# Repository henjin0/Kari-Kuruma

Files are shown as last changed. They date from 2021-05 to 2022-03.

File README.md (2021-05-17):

# Kari-Kuruma
Kari-Kuruma:Easy Constructing toy car for Prototyping.

簡単に組み立てられるプロトタイピング向けラジコンカー車体

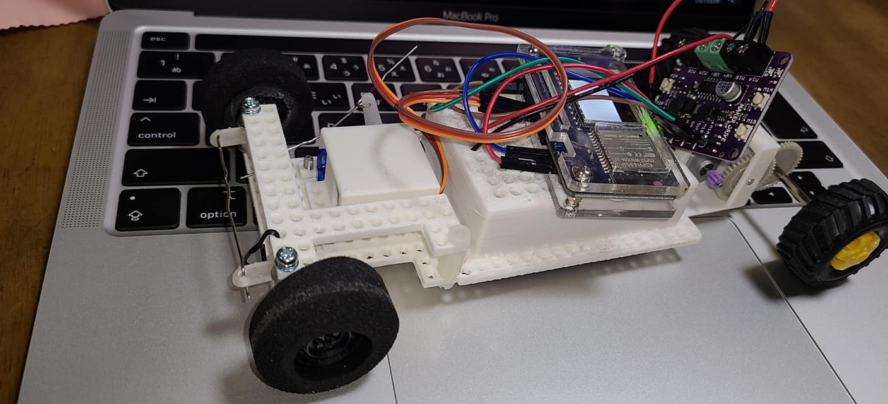
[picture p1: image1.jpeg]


# What is Kari-Kuruma?
Kari-Kuruma is an A5 size toy car body that can be created using 3D printing. The Kari-Kuruma can be easily assembled with Raspberry Pi or other circuit boards and various sensors such as cameras.
Also, parts that are not available through 3D printing can be easily obtained from sources such as TAMIYA.
This makes it possible to avoid as much as possible the risk of parts being out of supply.

Kari-Kurumaは3Dプリンティングで作成できるA5サイズのプロトタイピング向けラジコンカー車体で、Raspberry Piなどの基板やカメラなどの各種センサ類の組付けが容易にできます。
また、3Dプリンティングで手に入らない部品はTAMIYAなどから簡単に入手でき、部品のディスコンなどに振り回されないようにしました。

# Other assembly parts
The links are examples.

リンク先は一例です。

- [TAMIYA GEAR SET Item No:70239 (42T/12T)](https://www.tamiya.com/japan/products/70239/index.html)
- [TAMIYA AO-1001 FA-130 motor](https://www.tamiya.com/japan/products/94380/index.html)
or
- [MABUCHI FA-130RA motor](https://www.mabuchi-motor.co.jp/motorize/branch/motor/)
- [motor driver(何かしらのモータドライバ)](https://www.cytron.io/p-maker-drive-simplifying-h-bridge-motor-driver-for-beginner)

- [TowerPro SG-90 Servo motor](https://akizukidenshi.com/catalog/g/gM-08761/)
- [TAMIYA THREADED SHAFT SET (only using φ3(23mm))](https://www.tamiya.com/japan/products/70182/index.html):2 screws(ネジ2本)
- [M3x18 Machine Screw(M3x18 mmの機械ネジ)](https://www.amazon.com/dp/B07D5V279W/ref=cm_sw_em_r_mt_dp_WT2JPND0KJ9E13ZG9NET):2 screws(ネジ2本)
- [M3x10 Machine Screw(M3x10 mmの機械ネジ)](https://www.amazon.com/dp/B07MF3RN7M/ref=cm_sw_em_r_mt_dp_0NSJJ36C3078DVDZV988):6 screws(ネジ6本)
- [Wire link Arm A and B（Please see below.）](https://github.com/henjin0/Kari-Kuruma#how-to-build-wire-link-arm)

- [4 Slot AAA Battery Holder](https://akizukidenshi.com/catalog/g/gP-00735/)

# How to make Wire link arm.
Wire link arm are made two paper clips(ex:https://www.askul.co.jp/p/8188431/).

2つのペーパークリップ(針金クリップ)をつかってWire link armを作ります。

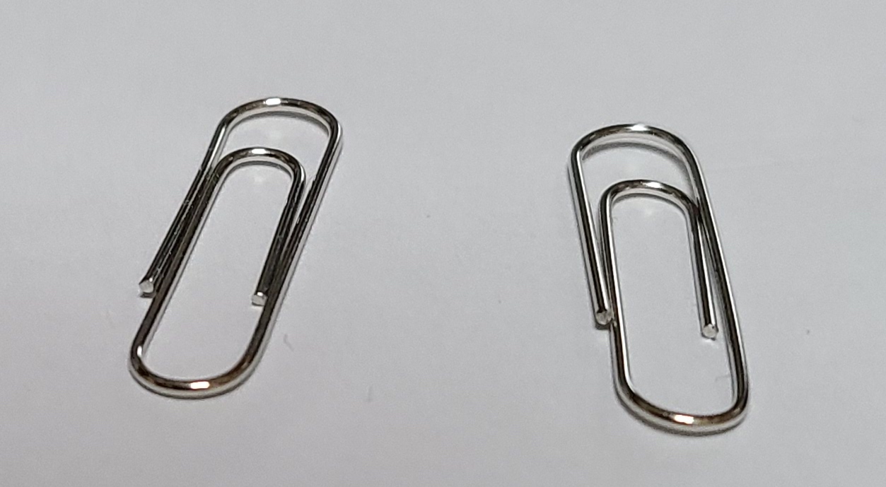
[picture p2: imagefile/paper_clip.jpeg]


1. Bend two paper clips into straight bar wires. 2つのクリップを折り曲げて直線状にします。

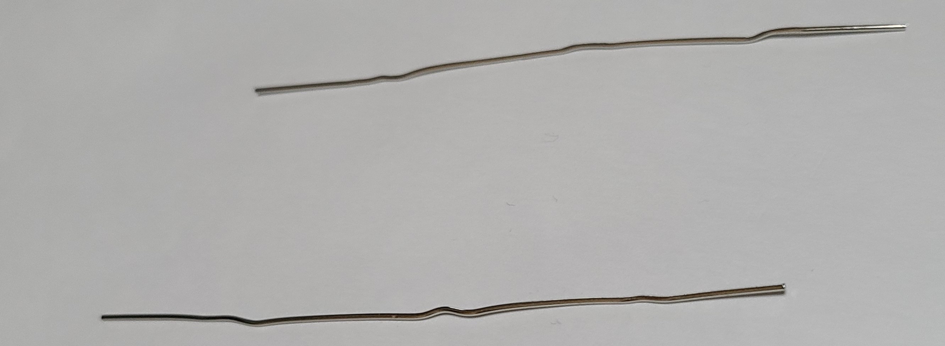
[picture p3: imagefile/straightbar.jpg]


## How to make Wire link arm A

2. Cut one wire to length of about 64 mm. 一つをおおよそ64 mmにカットします。

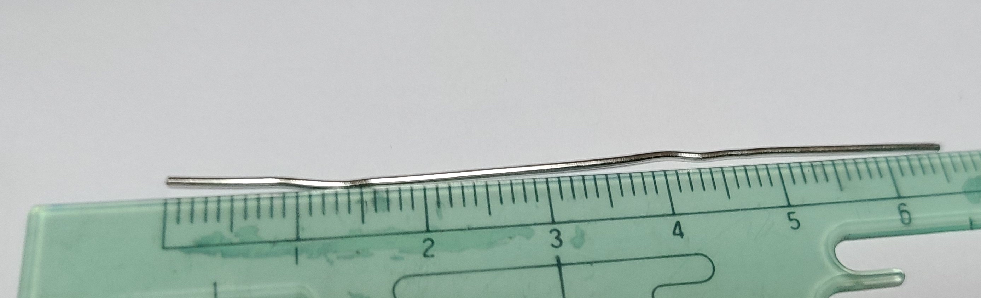
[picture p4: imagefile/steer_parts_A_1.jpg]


3. Bend 64 mm wire as shown in the figure below. 64 mmにカットしたものを下の写真のように折り曲げます。

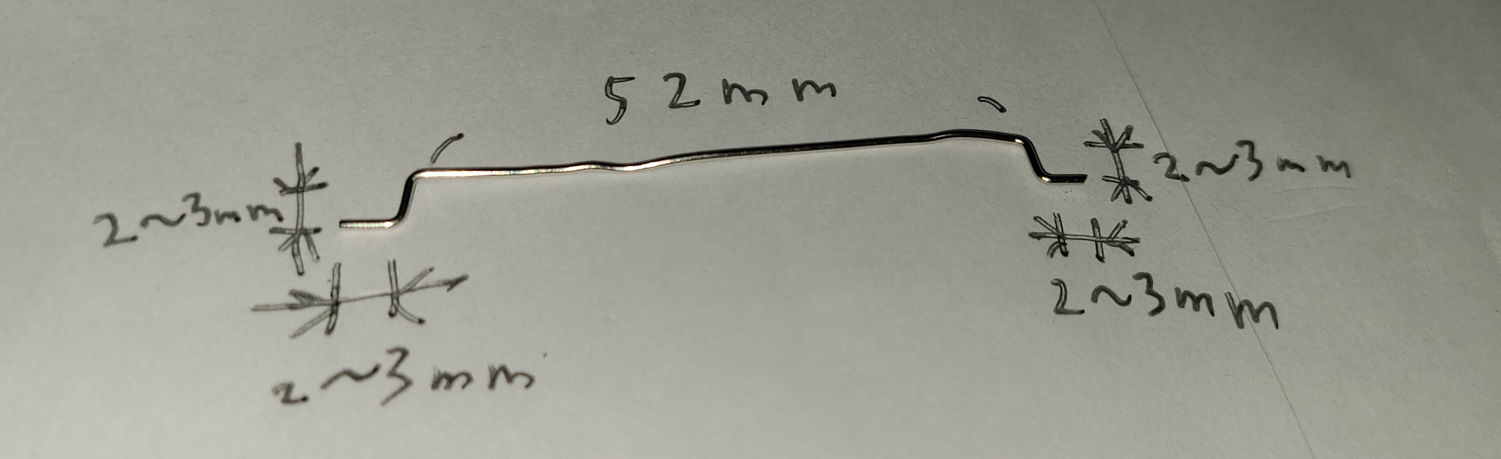
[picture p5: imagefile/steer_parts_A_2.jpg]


## How to make Wire link arm B

4. Cut another wire to length of about 52 mm. もう一つをおおよそ52 mmにカットします。

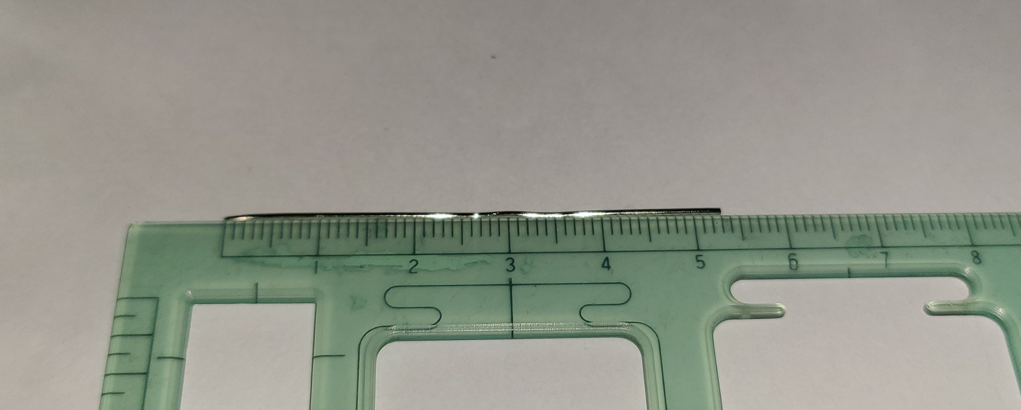
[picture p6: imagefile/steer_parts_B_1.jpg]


5. Bend another wire as shown in the figure below. 52 mmにカットしたものを下の写真のように折り曲げます。

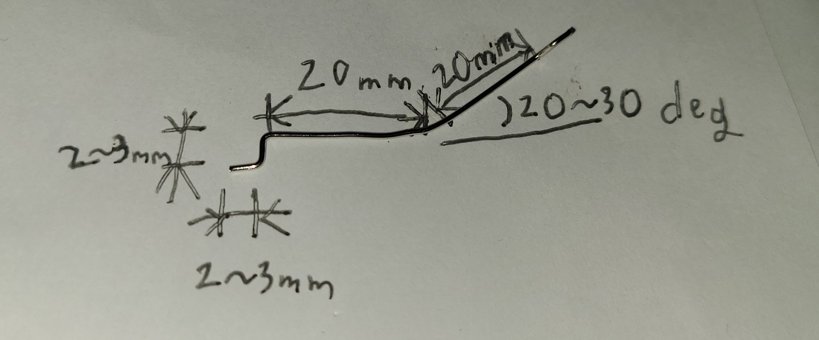
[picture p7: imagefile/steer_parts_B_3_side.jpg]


After bending to about 20 degrees parts, bend wire as shown in the figure below. 20度に折り曲げた先の部位は下の写真のように折り曲げます。

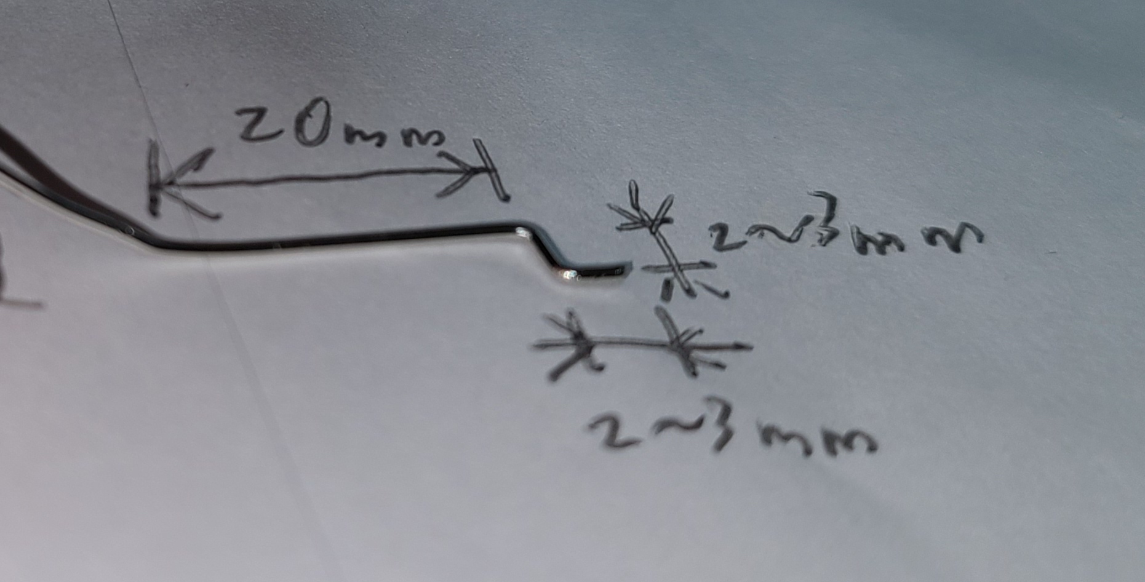
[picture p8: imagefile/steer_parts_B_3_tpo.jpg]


Creation of Wire link arm is complete. Parts cut to 64 mm :Wire link arm A are upper parts, and parts cut to 52 mm :Wire link Arm B are parts that transmit the driving force of steering from the servo motor to the upper.

これでWire link armの作成は完了です。64 mmにカットした部品(Wire link arm A)はアッパー部品に、52 mmにカットした部品(Wire link arm B)はサーボからアッパーへステアの駆動力を伝えるパーツになります。

# Constructing images

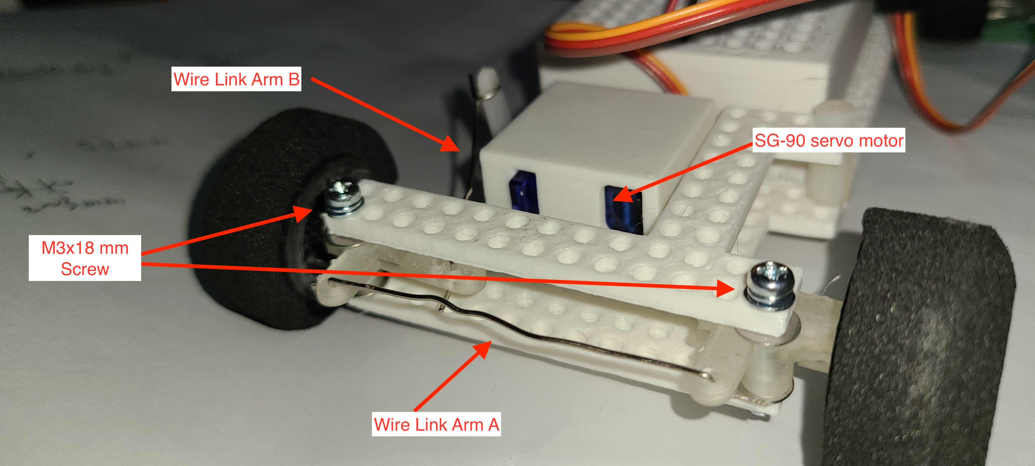
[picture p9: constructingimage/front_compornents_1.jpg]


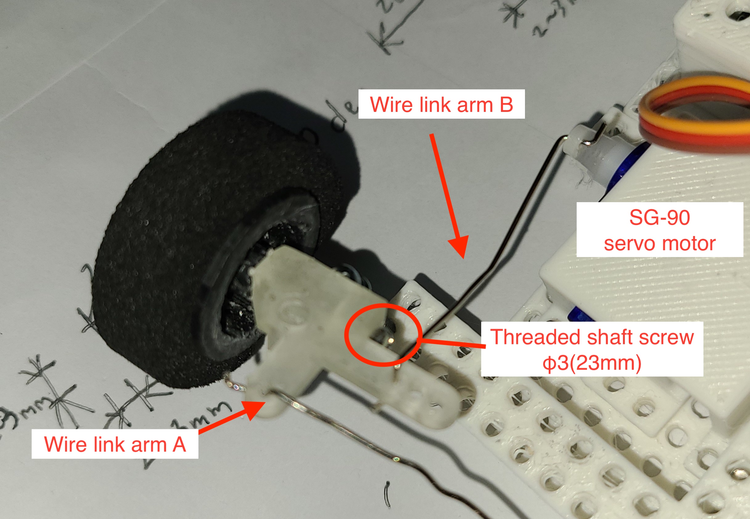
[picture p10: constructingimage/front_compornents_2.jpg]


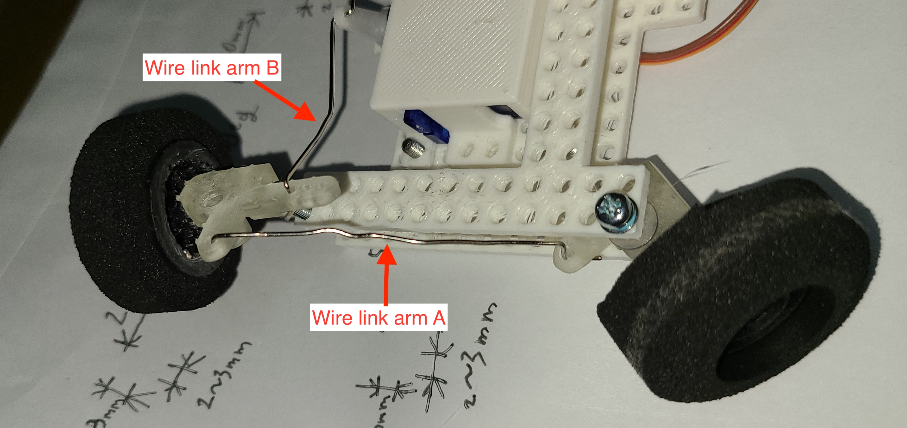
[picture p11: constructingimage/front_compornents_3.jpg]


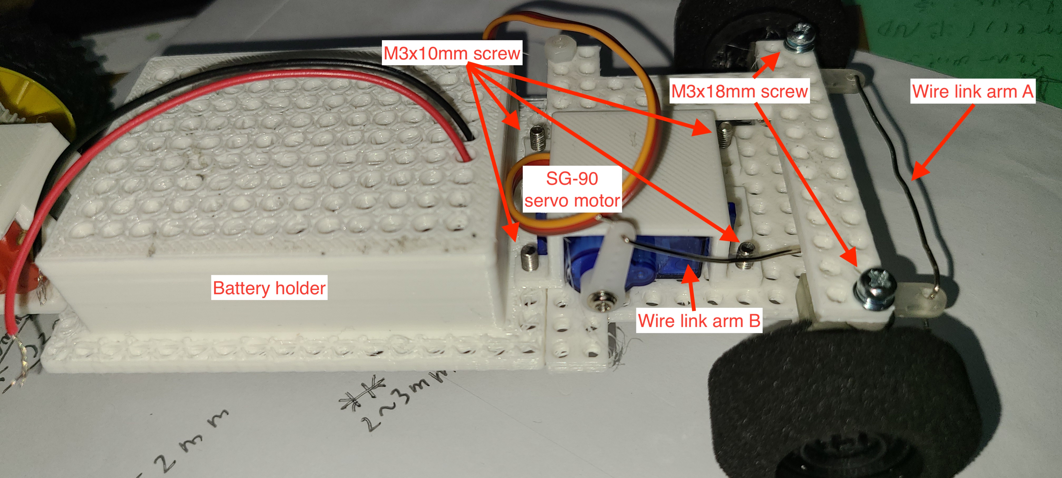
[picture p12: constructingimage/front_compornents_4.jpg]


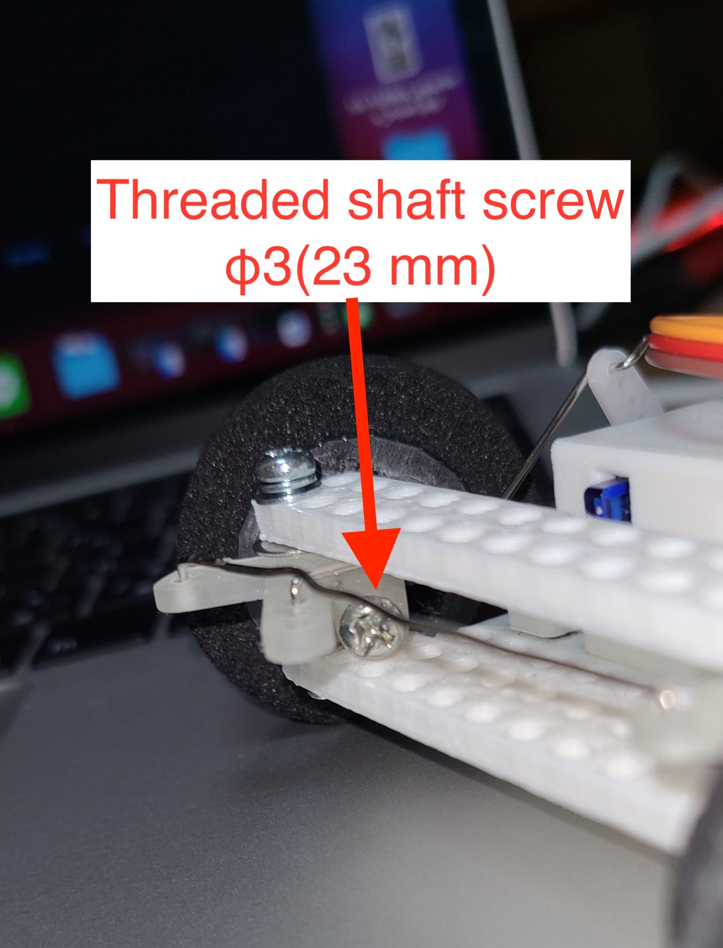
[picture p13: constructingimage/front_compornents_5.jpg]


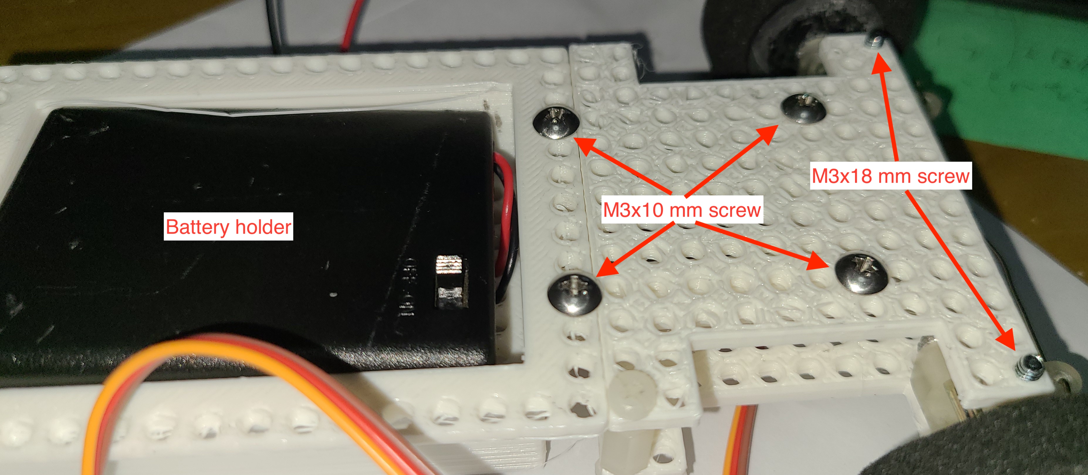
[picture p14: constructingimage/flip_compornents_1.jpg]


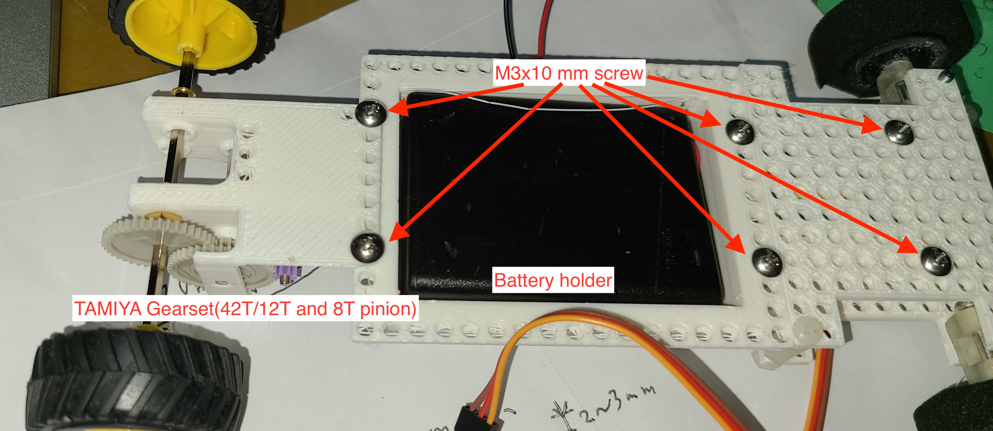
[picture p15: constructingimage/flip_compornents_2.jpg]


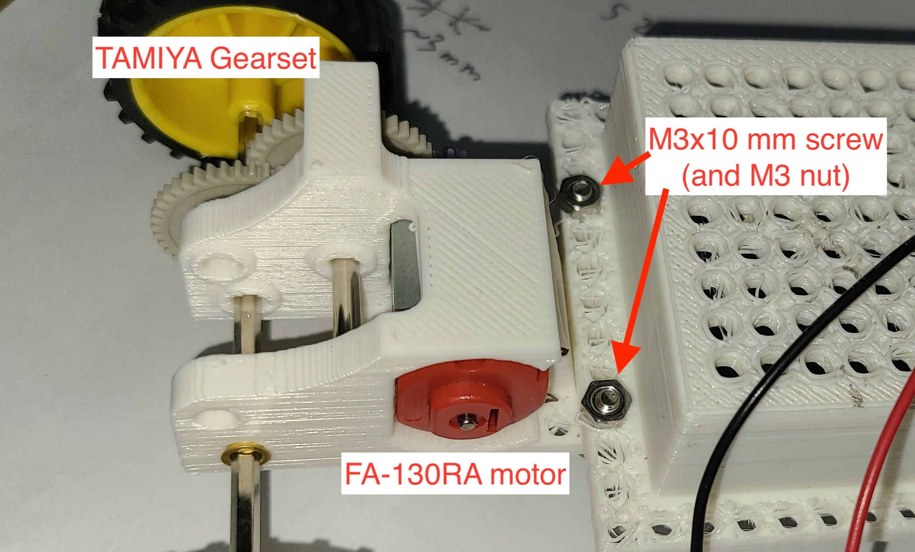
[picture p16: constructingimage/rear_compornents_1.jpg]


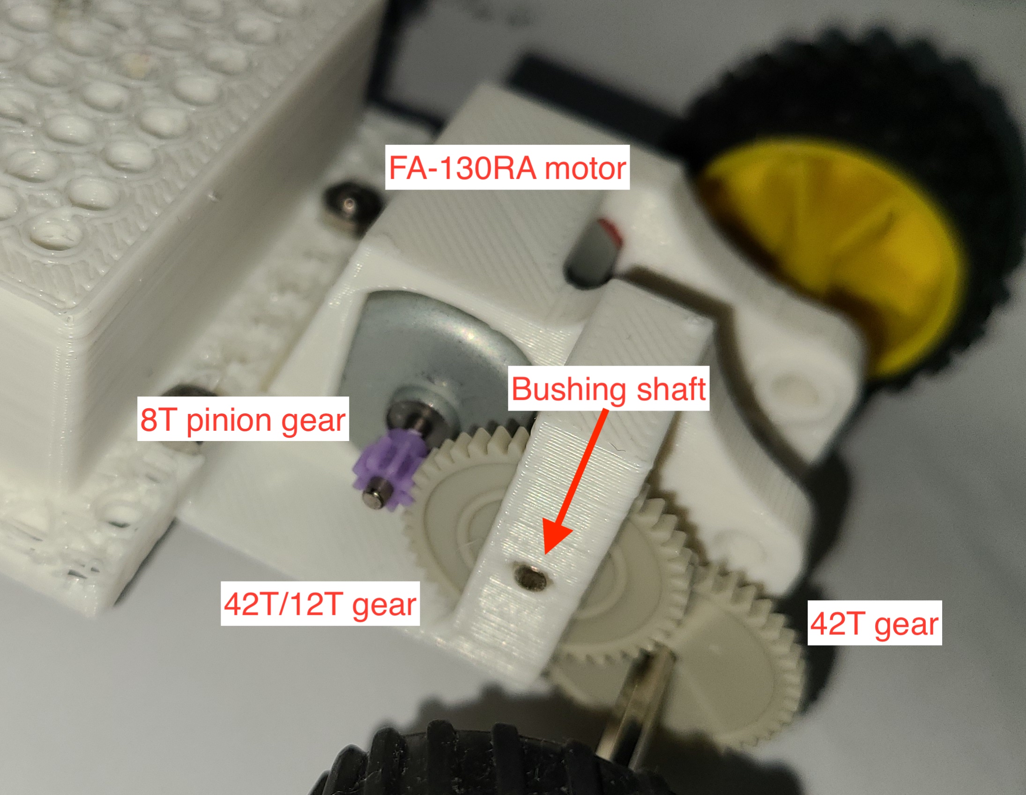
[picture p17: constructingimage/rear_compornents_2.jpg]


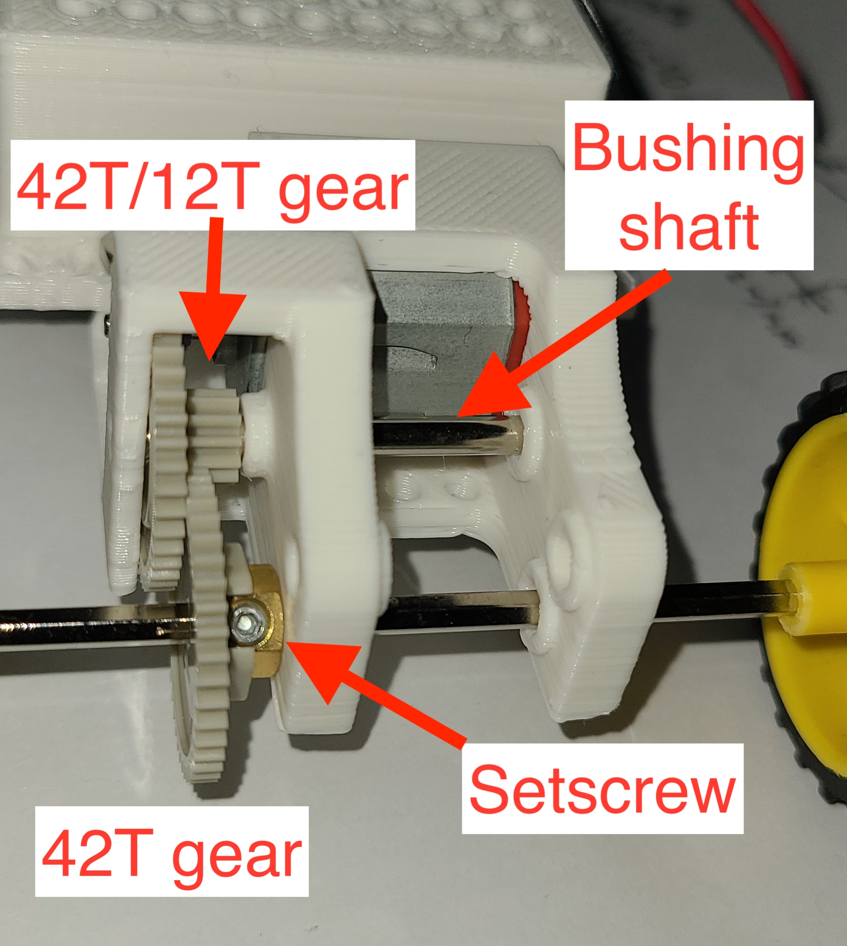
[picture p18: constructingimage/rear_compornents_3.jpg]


# License
Please see [LICENSE](https://github.com/henjin0/Kari-Kuruma/blob/main/LICENSE).

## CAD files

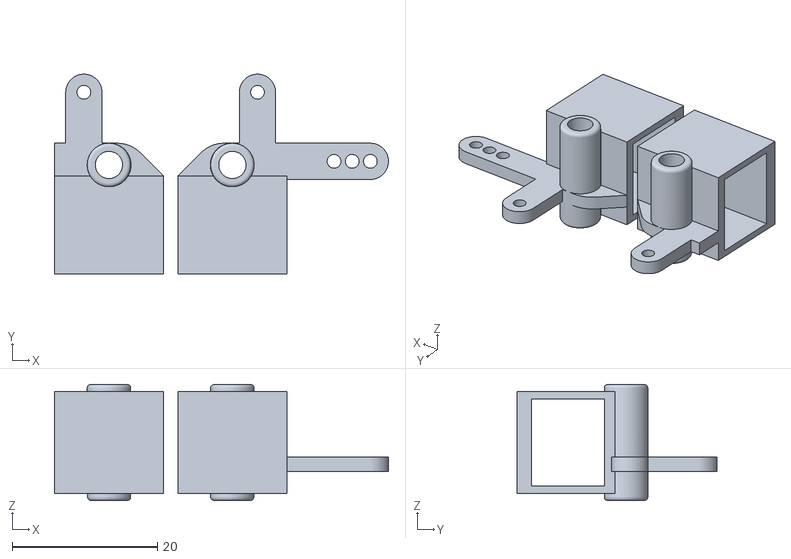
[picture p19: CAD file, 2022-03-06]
Steer_Upper_N20_motor.stl
46.0 x 27.5 x 16.0

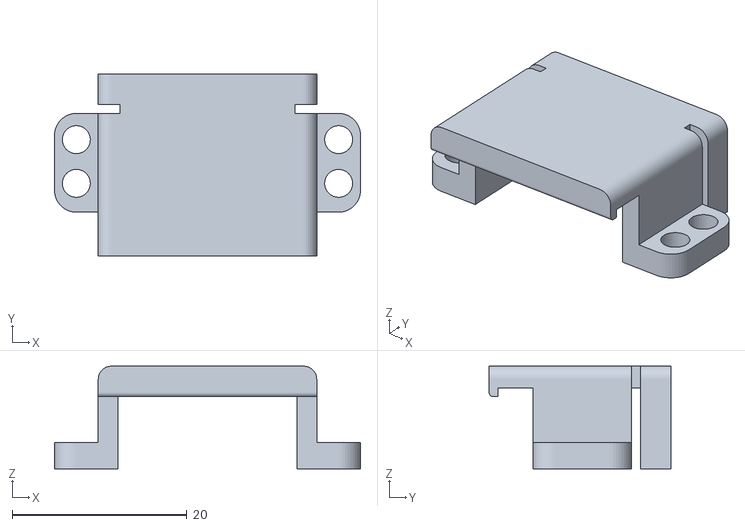
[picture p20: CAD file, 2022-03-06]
FS0403_servo_bracket.stl
35.0 x 20.8 x 11.8

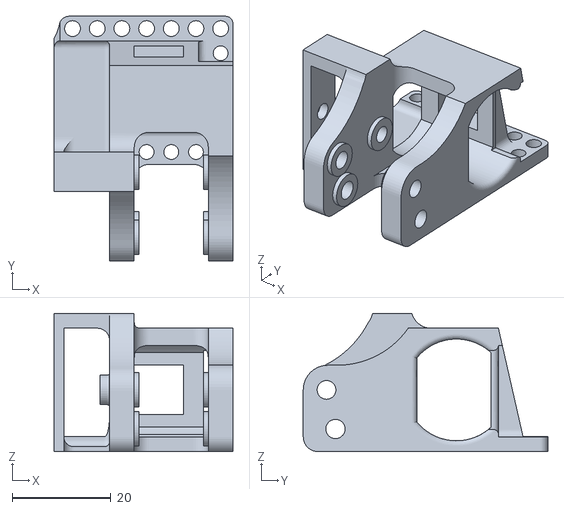
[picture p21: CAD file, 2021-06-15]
FA-130RA_TAMIYA_70239_No.239_Gearbox_with_hatome.stl
36.2 x 49.5 x 28.0

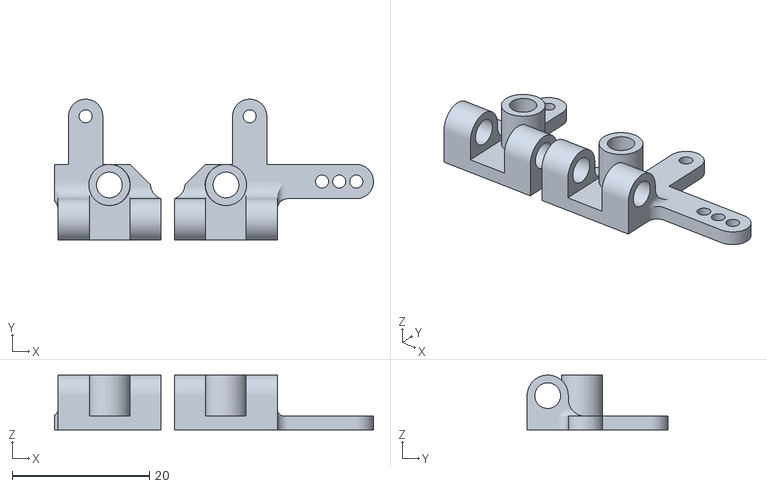
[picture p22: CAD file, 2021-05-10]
steer_upper.stl
46.5 x 20.5 x 8.00

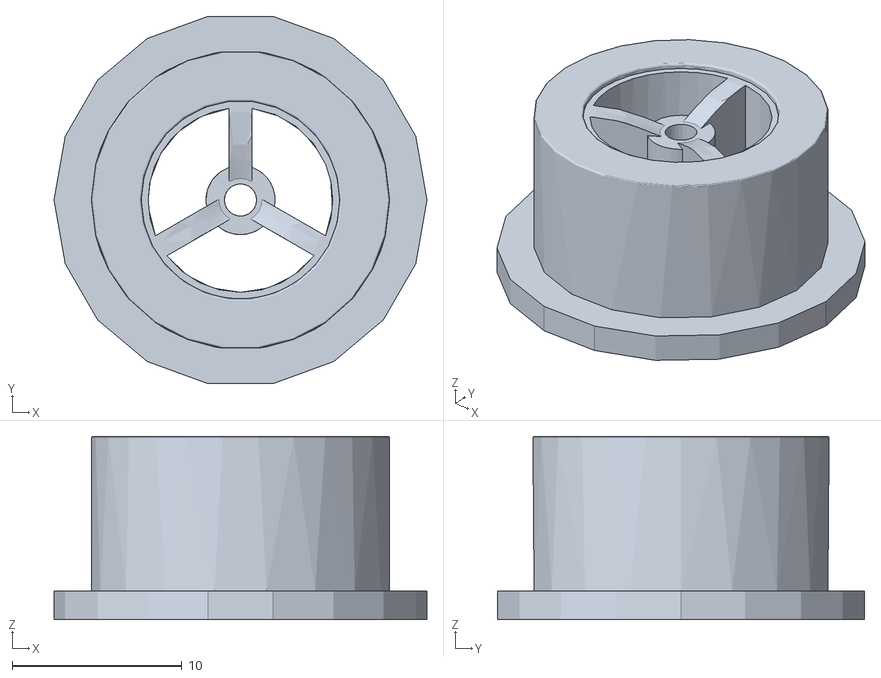
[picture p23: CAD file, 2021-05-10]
wheel1.stl
22.0 x 21.7 x 10.8

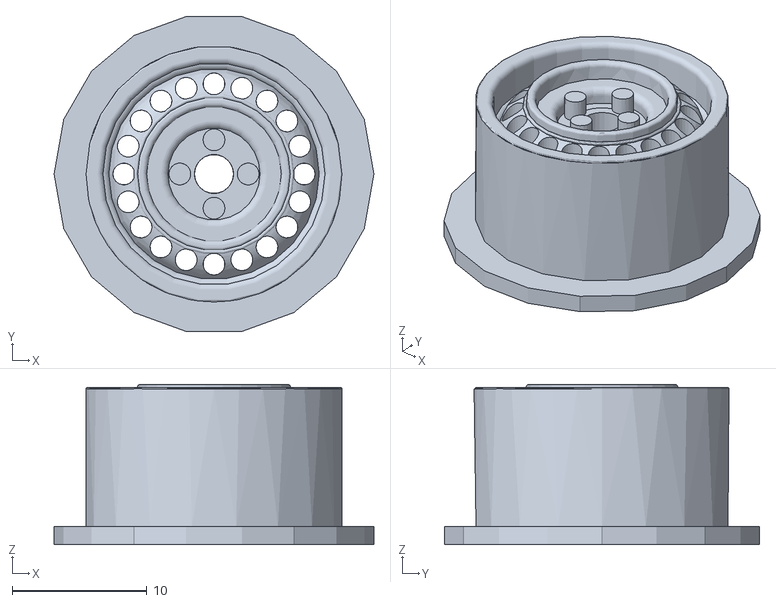
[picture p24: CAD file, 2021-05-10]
wheel2.stl
23.8 x 23.4 x 11.9

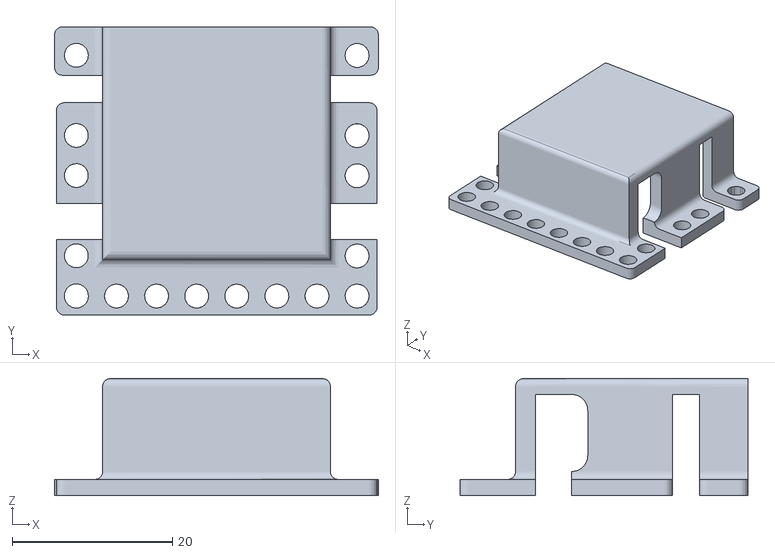
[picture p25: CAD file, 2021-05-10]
servo_bracket.stl
40.4 x 35.9 x 14.6

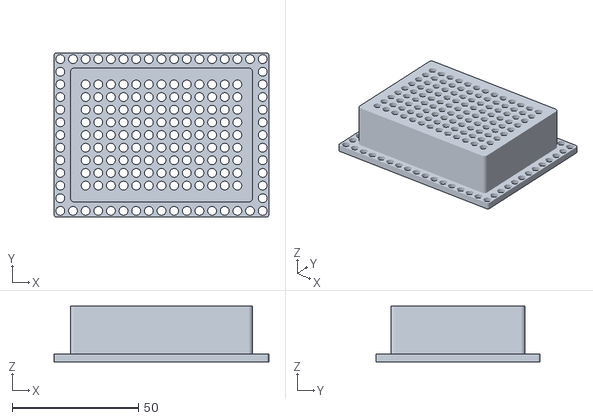
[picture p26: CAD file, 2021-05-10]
battery_bracket.stl
85.0 x 65.0 x 22.0

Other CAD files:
FA-130RA_TAMIYA_70239_No.239_Gearbox.stl

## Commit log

2021-05-10 add 3d compornents file.
    [FA-130RA_TAMIYA_70239_No.239_Gearbox.stl, battery_bracket.stl, servo_bracket.stl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]
2021-06-15 Add files via upload
    Considering TAMIYA eyelet(AO-1049) assembly
    [FA-130RA_TAMIYA_70239_No.239_Gearbox_with_hatome.stl]
2022-03-06 サーボモーターFS0403向けブラケットを追加
    [FS0403_servo_bracket.stl]
2022-03-06 Add files via upload
    四輪モーターあるいは前輪駆動にする際に使用するアッパーライト部品を追加
    [Steer_Upper_N20_motor.stl]
